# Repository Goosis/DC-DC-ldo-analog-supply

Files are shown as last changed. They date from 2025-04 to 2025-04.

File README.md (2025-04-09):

#  Dual-Stage Power Supply (DC-DC Buck + LDO)

**Input:** 6–10V DC  
**Output 1:** 4V @ 3.5A (Buck Converter)  
**Output 2:** 2.6V @ 1.7A (LDO Regulator)  
**Design Tool:** KiCad  
**ICs:** TPS56837H (Buck), TPS7A53B (LDO)

---

##  Description

This is a compact, efficient two-stage power supply designed for low-noise and high-current applications. It converts a 6–10V DC input into:

- 4V @ 3.5A via DC-DC Buck (TPS56837H)
- 2.6V @ 1.7A via LDO (TPS7A53B)

The design was based on official **Texas Instruments datasheets**, simulation tools, and PCB manufacturer guidelines. Great care was taken in layout, thermal management, and ground isolation.

---

##  Key Components

| Stage | IC | Vin | Vout | Iout Max | Notes |
|---|---|---|---|---|---|
| Buck  | TPS56837H | 6–10 V | 4 V  | 3.5 A | Synchronous, 500 kHz |
| LDO | TPS7A53B | 4 V | 2.6 V| 1.7 A | Ultra-low noise, high PSRR |

---

##  Layout Design vs TI Recommendation

This PCB layout was designed by following layout principles from the **TPS56837H datasheet**.

<table>
  <tr>
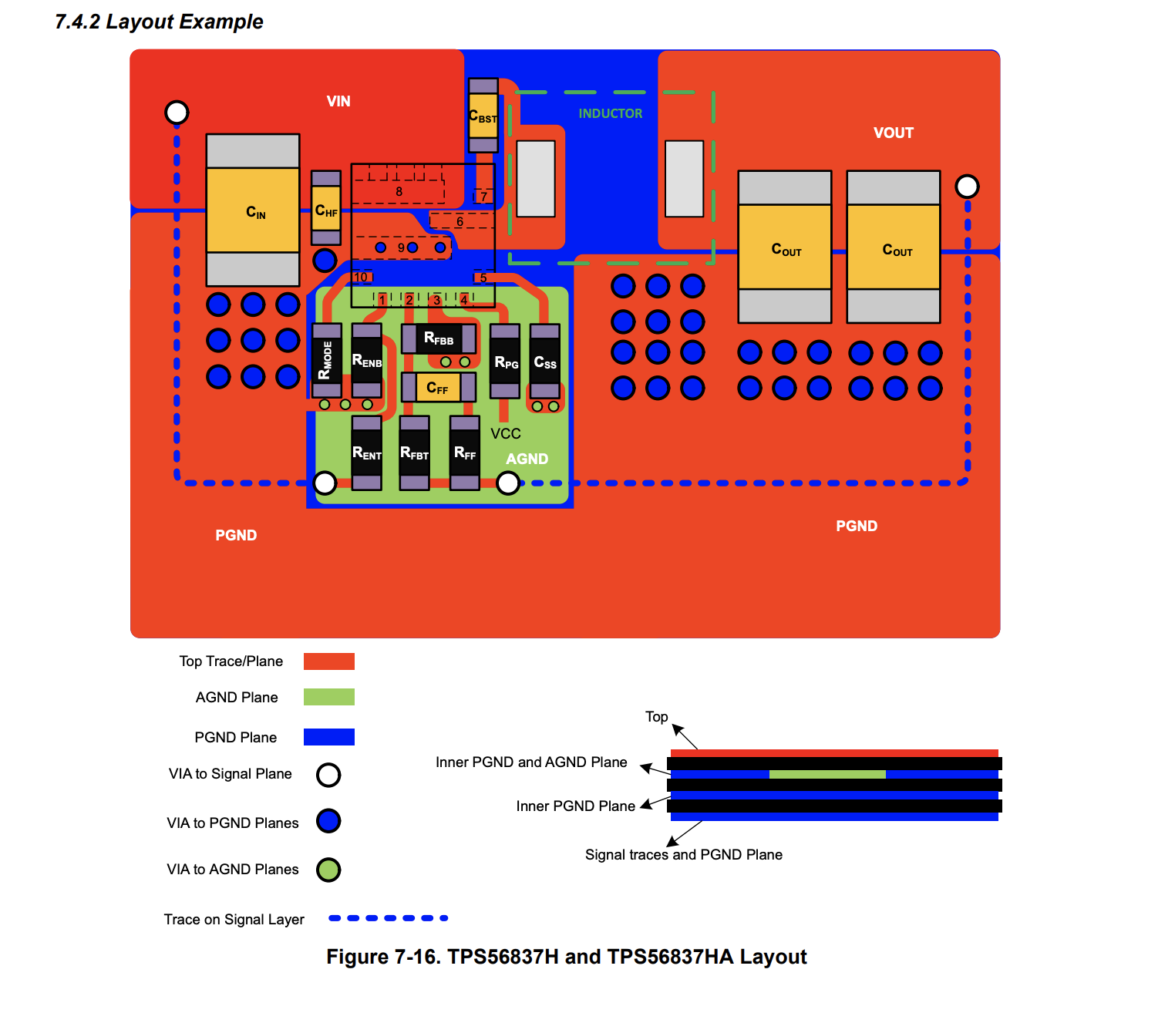
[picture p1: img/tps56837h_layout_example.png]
    <td><b>TI Recommended Layout</b><br/></td>
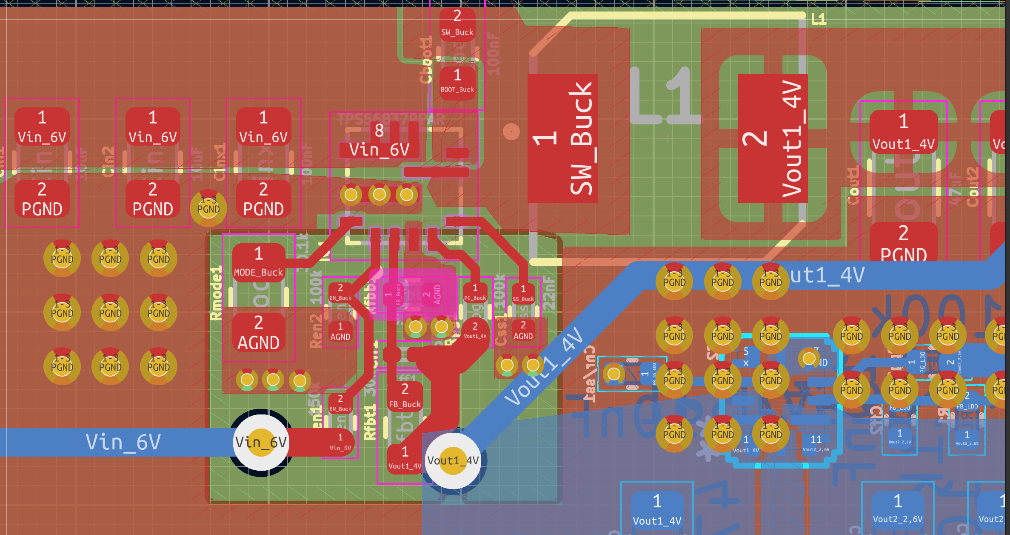
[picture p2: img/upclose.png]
    <td><b>My PCB Layout (KiCad)</b><br/></td>
  </tr>
</table>

 **Matched Design Features:**
- Short loops for high-current paths (Cin → SW → Inductor → Cout)
- Correct placement of decoupling capacitors near IC pins
- AGND and PGND separation via internal planes and via stitching
- Wide copper traces sized according to 3.5A requirement
- Respect of layout zones for analog feedback and control

---
---

##  PSpice Simulation

The design was simulated in PSpice using vendor-provided models for both the buck converter (TPS56837H) and LDO (TPS7A5301).  
This helped verify soft-start behavior, regulation stability, and output timing before fabrication.

<table>
  <tr>
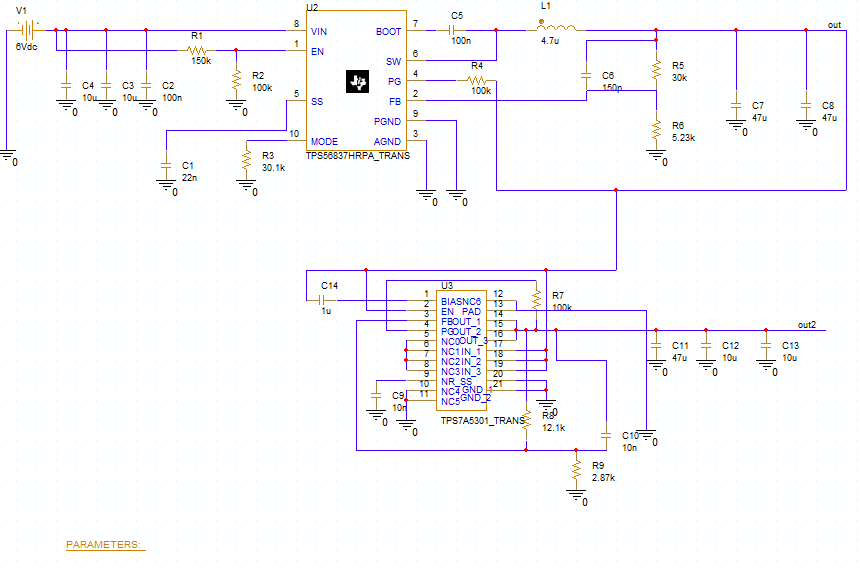
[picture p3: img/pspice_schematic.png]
    <td><b>Schematic (PSpice)</b><br/></td>
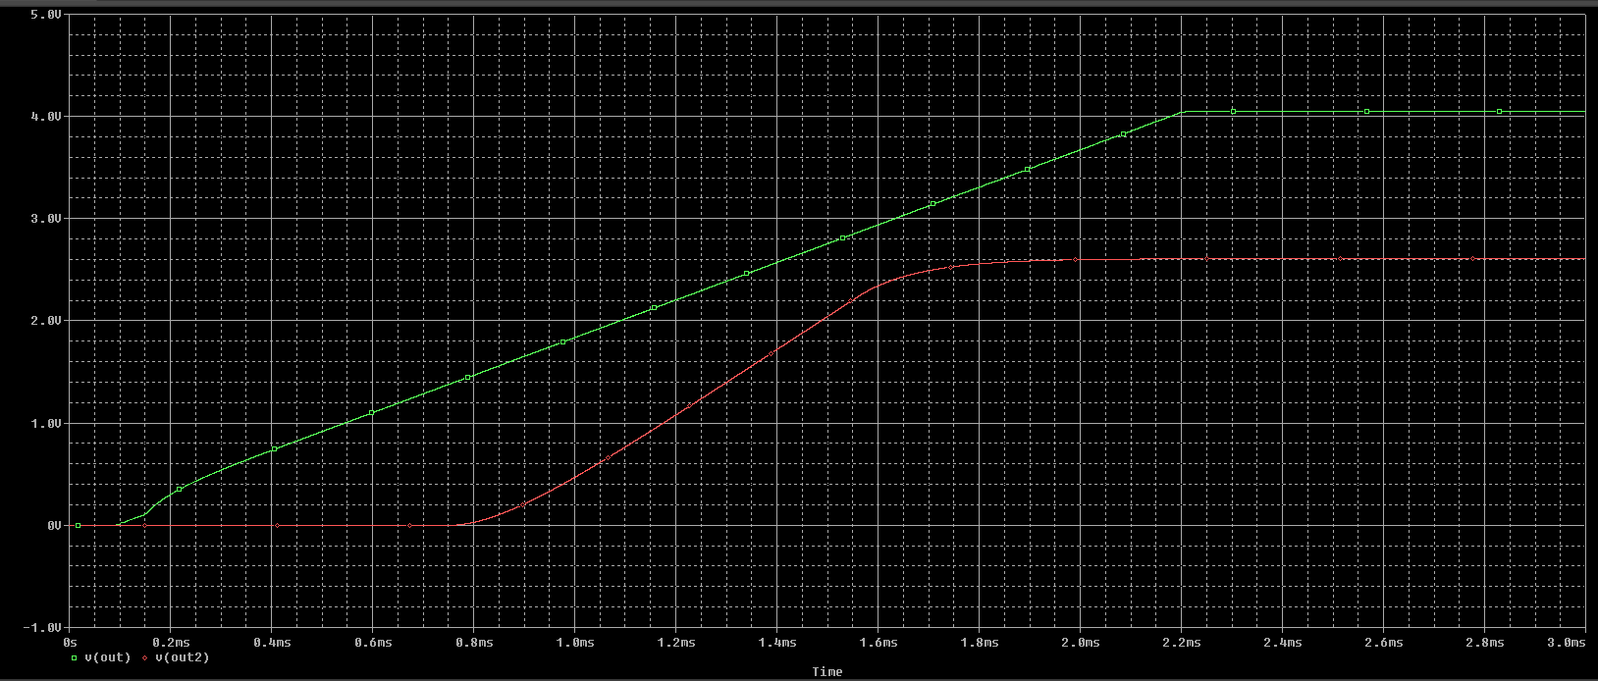
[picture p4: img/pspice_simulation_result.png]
    <td><b>Simulation Result</b><br/></td>
  </tr>
</table>

Green = Vout1 (4 V)  
Red = Vout2 (2.6 V)

The simulation shows proper soft-start ramp-up and sequential regulation, matching expectations.

Simulation files are aviable on my [Google Drive](https://drive.google.com/drive/folders/1zhOBsbE7j7mKasGqCcKV4JfBKCOTLMK9?hl=cs)

##  Images

### Schematic  
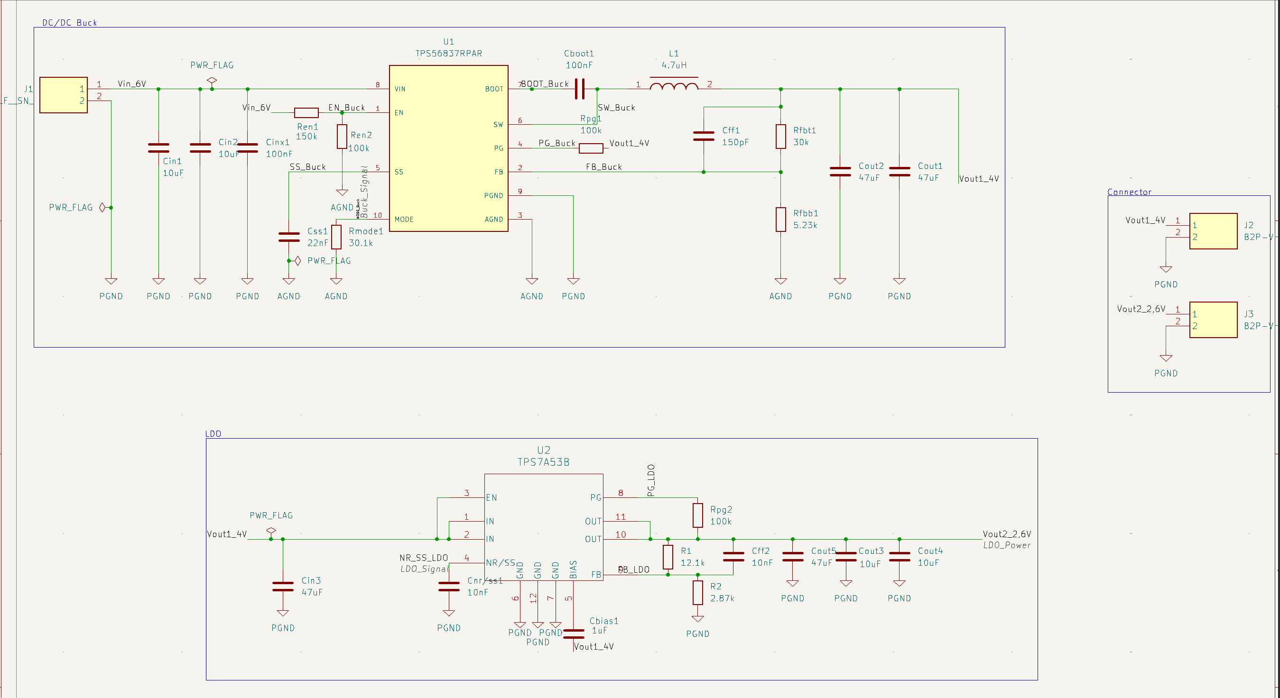
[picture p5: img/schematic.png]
schematic


### PCB Layout (Top Layer)  
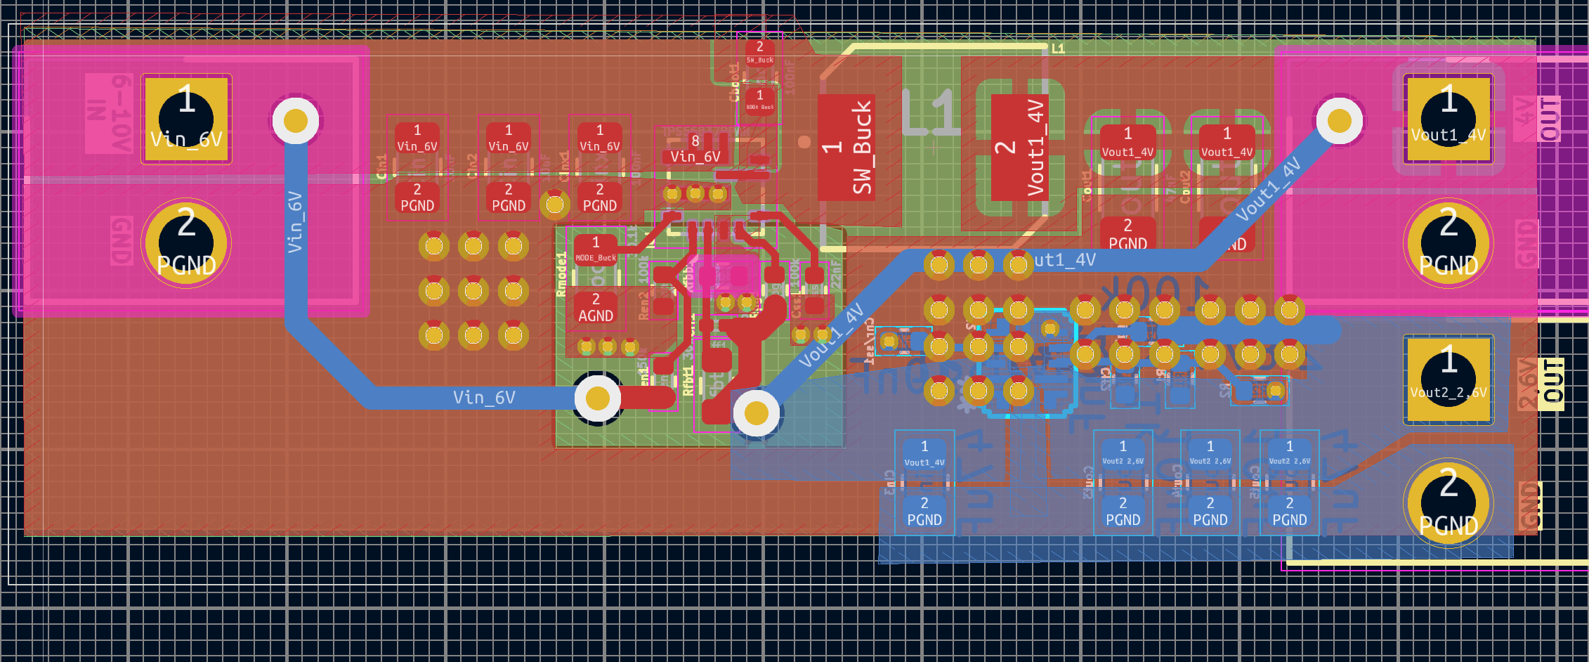
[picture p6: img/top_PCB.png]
PCB Top Layer


### 3D View  
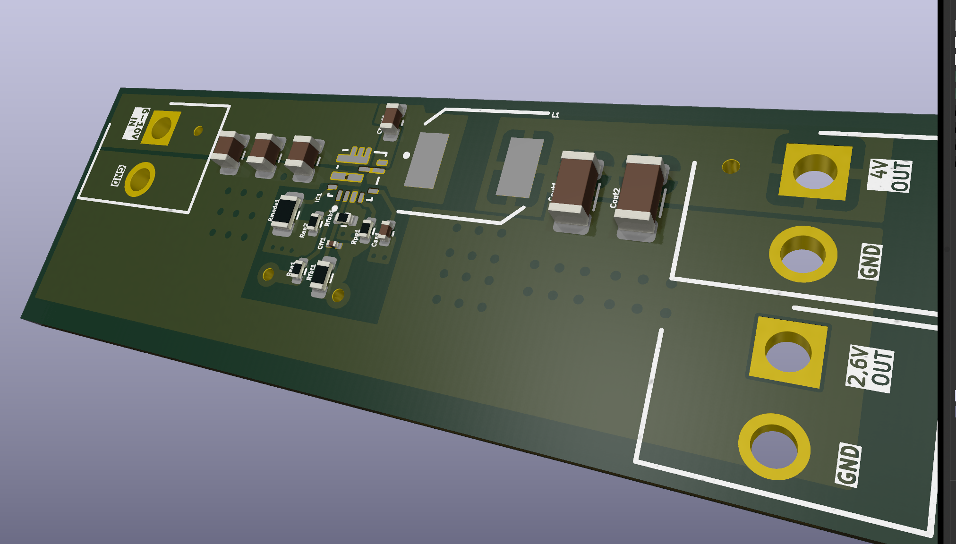
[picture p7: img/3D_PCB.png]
3D View


---

## ⚠️ Design Challenges & Fixes

###  LDO BIAS Pin Not Connected

In the first revision, the **BIAS pin** of the LDO (TPS7A53B) was left floating.  
According to [section 8.3.1.2 of the datasheet](https://www.ti.com/lit/ds/symlink/tps7a53b.pdf#page=19), this causes the output to **follow the input voltage** instead of regulating — which is exactly what happened.

📌 **Fix:** Connected BIAS to VIN (4 V) and added a 1 µF capacitor to GND, as recommended in the datasheet.

---

###  Incorrect EN Pin Logic on Buck Converter

Initially, the **EN pin** of the buck converter was connected to its own output (VOUT), assuming it would enable itself after power-up.  
However, this caused the converter to stay disabled at startup.

📌 **Fix:** Connected EN to VIN through a **resistor divider**, ensuring a valid logic-high signal at startup. This resolved the issue and allowed proper converter initialization.

---

###  TI-Provided Footprint Had Pad Issues

The **footprint from TI's UltraLibrarian export** for the TPS7A53B had issues:
- Some **pads were incorrectly shaped or numbered**
- **Routing was blocked** due to KiCad DRC violations

📌 **Fix:** Manually edited the footprint in **KiCad Footprint Editor** to:
- Adjust pad shapes and positions
- Fix pin numbering
- Ensure proper copper connection and DRC clearance

---

These issues were identified during layout review and early testing, and fixed in preparation for the next board revision.

---

##  Project Files

- `/schematic/` — KiCad schematic (`.kicad_sch`)  
- `/pcb/` — KiCad board layout (`.kicad_pcb`)  
- `/gerbers/` — Gerber files for fabrication  
- `/bom/` — Bill of Materials  
- `/pdf/` — PDF exports of schematic and layout

---

##  Tools & Calculators Used

- [TI Webench Power Designer](https://webench.ti.com/power-designer/)
- [ChipDip Voltage Divider Calculator](https://www.chipdip.ru/calc/voltage-divider)
- [Trace Width Calculator (AdvancedPCB)](https://www.advancedpcb.com/en-us/tools/trace-width-calculator/)
- [Via Properties Calculator (911EDA)](https://www.911eda.com/pcb-design-calculators/via-properties-calculator/)
- [JLCPCB Capabilities](https://jlcpcb.com/capabilities/pcb-capabilities)

---

## ✅ Project Status

- [x] Schematic complete  
- [x] PCB layout finished  
- [x] BOM generated  
- [x] Layout verified vs datasheet  
- [ ] PCB ordered  
- [ ] Load testing  
- [ ] Ripple and thermal validation

---

## 📚 References

- [TPS56837H Datasheet](https://www.ti.com/product/TPS56837H)
- [TPS7A53B Datasheet](https://www.ti.com/product/TPS7A53B)
- [KiCad Docs](https://docs.kicad.org/)

---

> 💬 Suggestions, improvements, or critiques are welcome. This design is still open for review.

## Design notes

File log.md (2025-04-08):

## Day 1 – March 25

- Defined system requirements: Vin = 6–10 V, Vout1 = 4 V, Iout1 = 3.5 A, Vout2, Iout2 = 2.6 V
- Chose a two-stage power topology: DC-DC buck converter followed by a low-noise LDO
- Selected components:
  - **TPS56837H** (buck converter, 6 A)
  - **TPS7A53B** (LDO regulator, 3 A)
- For **TPS56837H**:
  - Used the [TI WEBENCH Power Designer](https://webench.ti.com/) to calculate values for external components (inductor, input/output capacitors, feedback resistors)
  - Reviewed layout and footprint recommendations in the datasheet (package, thermal pad, via placement)
- For **TPS7A53B**:
  - Manually calculated the feedback resistor values using the datasheet formula:
    \[
    V_{OUT} = V_{REF} \cdot \left(1 + \frac{R_1}{R_2} \right)
    \]
    with V<sub>REF</sub> = 0.5 V
  - Selected R1 = 12.1 kΩ, R2 = 2.87 kΩ to achieve Vout ≈ 2.6 V
  - Calculated feedforward capacitor C<sub>FF</sub> ≈ 1.3 nF to place the zero around 10 kHz

## Day 2 – March 27

- **Completed schematic design** for the power system, incorporating the DC-DC buck converter (TPS56837H) followed by the LDO (TPS7A53B).
- **Recalculated component values** for a few parts based on datasheet recommendations.
  - **Updated feedback resistor values** to fine-tune the output voltage for the LDO (TPS7A53B).
  - **Validated output capacitors**: 47uF and 10uF for both input and output filters to meet the recommended capacitance values.
- **Checked for proper component placement and connections** in the schematic:
  - Verified that feedback resistors, capacitors, and power lines are connected correctly.
  - Ensured proper grounding and component orientation for thermal performance and efficiency.
  - **Fixed errors** related to component placement in the layout for power and ground planes.
- **No major issues** found in the design; proceeding with the next steps of layout design and preparation for PCB.

### Day 3 – March 31

- Finalized full BOM for the power subsystem  
- Fixed EN pin bug on the buck converter (added voltage divider from Vin)  
- Created custom net classes in KiCad (`Buck_Power`, `LDO_Signal`, etc.)  
- Assigned nets and set trace widths based on datasheet recommendations  

**Day 4 – April 1**  
- Placed components for the TPS56837H on the PCB.  
- Decided to replace the connectors, as the current ones are too large for a compact layout.  
- Replaced the inductor entirely — the previous one was too large, and the new one is $2 cheaper.
- Marked several capacitors and resistors (0805) to be replaced with 0402 packages for space optimization and better routing.  
→ Will update these footprints and revise the BOM tomorrow.

### Day 5 – April 2

- Had a productive 7-hour session today.  
- Completed component placement in sections and connected all components.  
- Changed the CBOOT1 capacitor package from 0402 to 0603 to comply with clearance rules.  
- Encountered footprint issues for ICs – learned how to modify footprints using the footprint editor.  
- Learned to work with a 4-layer PCB stackup.  
- Tomorrow: will label all components clearly and update the BOM.

- ### Day 6 – April 4
- Updated BOM

- ### Day 6 – April 4
- Completed README.md
- Uploaded files to github

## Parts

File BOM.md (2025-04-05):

### Capacitors

| Reference | Quantity | Value | Footprint | Manufacturer | Price  | Total  | Link |
|---|---|---|---|---|---|---|---|
| Cff1 | 1 | 150pF  | 0603 | KEMET | $0.100 | $0.10  | [Link](https://cz.mouser.com/ProductDetail/Coilcraft/MSS1048-472NLC?qs=zCSbvcPd3pYtZ57pXl6AJA==) |
| Cout1,Cout2 | 2 | 47uF | 1206 | TDK | $0.871 | $1.74  | [Link](https://cz.mouser.com/ProductDetail/TDK/C3216X5R1E476M160AC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) |
| Cout3,Cout4 | 2 | 10uF | 0805 | TAIYO YUDEN  | $0.271 | $0.54  | [Link](https://cz.mouser.com/ProductDetail/TAIYO-YUDEN/TMK212BBJ106MGHT?qs=sBf/b4nBSlfab8x4Ir6OCA==) |
| Cboot1 | 1 | 100nF  | 0603 | KYOCERA AVX | $0.171 | $0.17  | [Link](https://eu.mouser.com/ProductDetail/KYOCERA-AVX/0201YD104KAT2A?qs=%252BdQmOuGyFcFSHNmmxKg%252B7A%3D%3D) |
| Cout5, Cin3 | 2 | 47uF | 0805 | TAIYO YUDEN  | $0.731 | $1.46  | [Link](https://cz.mouser.com/ProductDetail/TAIYO-YUDEN/MLASL21GBB5476MTNA01?qs=tlsG/Ow5FFgOkGqgSpO4Uw==) |
| Cinx1 | 1 | 100nF  | 0805 | MuRata | $0.311 | $0.31  | [Link](https://cz.mouser.com/ProductDetail/Murata-Electronics/GCM21BR71H104KA37L?qs=HH0X151LQklyB3m9dD31Bw%3D%3D) |
| Cin1, Cin2 | 2 | 10uF | 0805 | MuRata | $0.151 | $0.30  | [Link](https://cz.mouser.com/ProductDetail/Murata-Electronics/GRM21BR61E106MA73L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) |
| Css1 | 1 | 22nF | 0402 | MuRata | $0.100 | $0.10  | [Link](https://cz.mouser.com/ProductDetail/Murata-Electronics/GRM155R71C223KA01D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) |
| Cnr/ss1, Cff2 | 2 | 10nF | 0402 | TAIYO YUDEN  | $0.095 | $0.19  | [Link](https://eu.mouser.com/ProductDetail/TAIYO-YUDEN/MSASE042SB5103KWNA01?qs=tlsG%2FOw5FFgLDNWOywOLGg%3D%3D) |

### ICs

| Reference | Quantity | Value | Footprint | Manufacturer | Price  | Total  | Link |
|---|---|---|---|---|---|---|---|
| TPS56837H | 1 | - | TPS56837HARPAR | Texas Instruments  | $2.061 | $2.06  | [Link](https://www.ti.com/product/TPS56837H#all) |
| TPS7A53B | 1 | - | TPS7A53B | Texas Instruments  | $2.404 | $2.40  | [Link](https://www.ti.com/product/TPS7A53B) |

### Other

| Reference | Quantity | Value | Footprint | Manufacturer | Price  | Total  | Link |
|---|---|---|---|---|---|---|---|
| L1 | 1 | 4.7uH  | SPM6530 | TDK | $0.912 | $0.912  | [Link](https://eu.mouser.com/ProductDetail/TDK/SPM6530T-4R7M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) |
| J1, J2, J3  | 3 | 2 pins  | - | Molex | $0.228 | $0.684  | [Link](https://eu.mouser.com/ProductDetail/Molex/26-60-4020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) |

### Resistors

| Reference | Quantity | Value | Footprint | Manufacturer | Price  | Total  | Link |
|---|---|---|---|---|---|---|---|
| Rpg1, Rpg2, Ren1 | 3 | 100kOhm | 0402 | VishayDale | $0.100 | $0.30  | [Link](https://cz.mouser.com/ProductDetail/Vishay-Dale/CRCW0402100KFKED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) |
| Ren2 | 1 | 150 kOhms | 0402 | YAGEO | $0.12 | $0.12  | [Link](https://cz.mouser.com/ProductDetail/Bourns/CR0402-FX-1503GLF?qs=sGAEpiMZZMtlubZbdhIBICGkyIRIR3aIoYCmJyeepGY%3D) |
| Rfbt1 | 1 | 30 kOhms  | 0603 | YAGEO | $0.111 | $0.11  | [Link](https://cz.mouser.com/ProductDetail/YAGEO/RC0603FR-0730KL?qs=diQw95jMAeNFr44yr782FQ%3D%3D) |
| Rfbb1 | 1 | 5.23 kOhms| 0402 | VishayDale | $0.100 | $0.10  | [Link](https://cz.mouser.com/ProductDetail/Vishay-Dale/CRCW04025K23FKED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) |
| R2 | 1 | 2.87kOhm  | 0402 | YAGEO | $0.124 | $0.12  | [Link](https://eu.mouser.com/ProductDetail/YAGEO/RC0100FR-072K87L?qs=tggtontpCXMGft6%252B2PgPnw%3D%3D) |
| R1 | 1 | 12.1kOhm  | 0402 | VishayDale | $0.171 | $0.17  | [Link](https://eu.mouser.com/ProductDetail/Vishay-Dale/CRCW010012K1FREL?qs=r5DSvlrkXmKL%252BfFur1RTrw%3D%3D) |
| Rmode1 | 1 | 30.1kOhm  | 0805 | KOA Speer | $0.233 | $0.23  | [Link](https://cz.mouser.com/ProductDetail/KOA-Speer/SG73P2ARTTD3012F?qs=Y0Uzf4wQF3ldSzmG%252BQ6ZTQ%3D%3D) |

**Total Cost: $12,14**

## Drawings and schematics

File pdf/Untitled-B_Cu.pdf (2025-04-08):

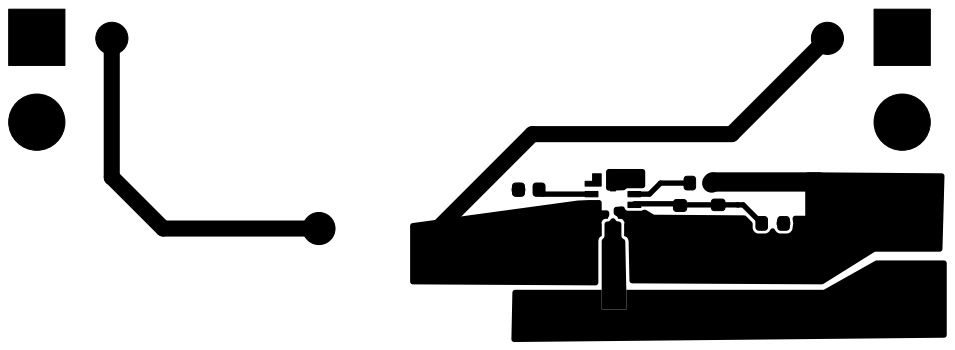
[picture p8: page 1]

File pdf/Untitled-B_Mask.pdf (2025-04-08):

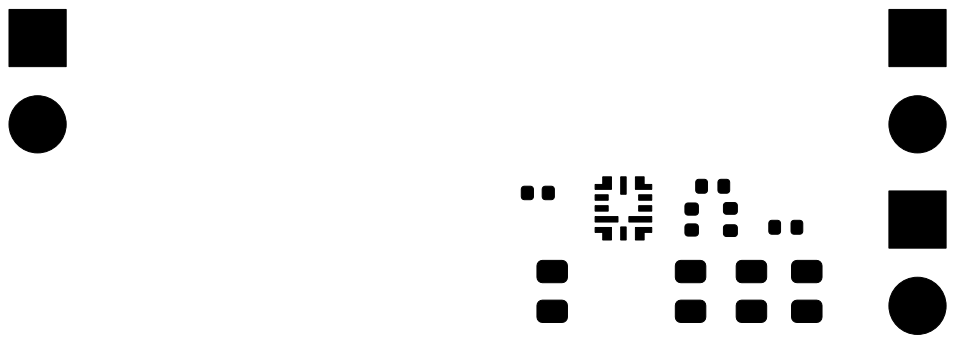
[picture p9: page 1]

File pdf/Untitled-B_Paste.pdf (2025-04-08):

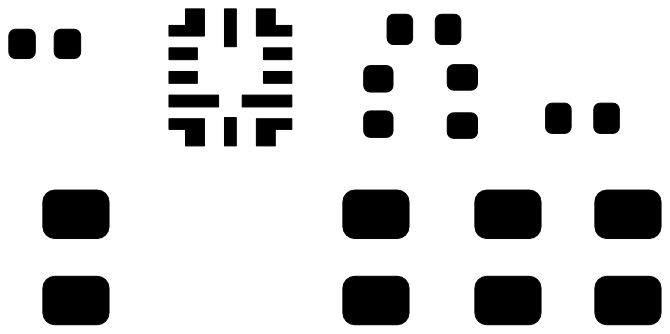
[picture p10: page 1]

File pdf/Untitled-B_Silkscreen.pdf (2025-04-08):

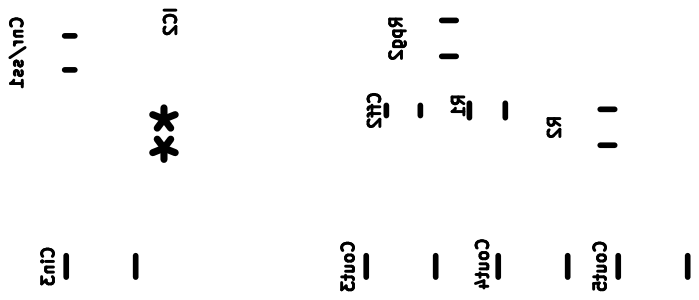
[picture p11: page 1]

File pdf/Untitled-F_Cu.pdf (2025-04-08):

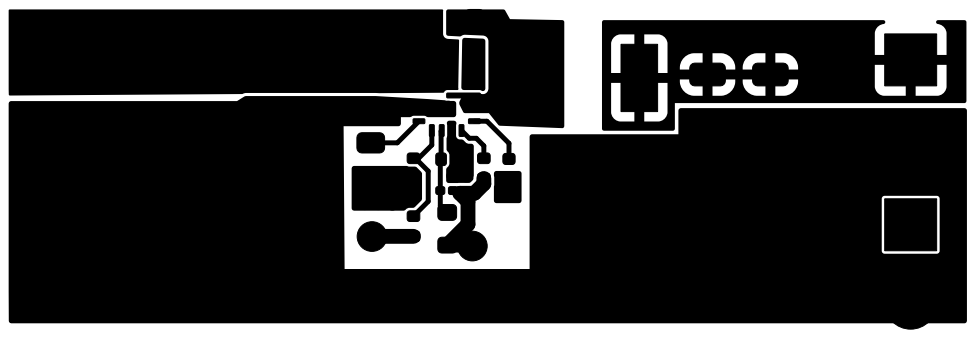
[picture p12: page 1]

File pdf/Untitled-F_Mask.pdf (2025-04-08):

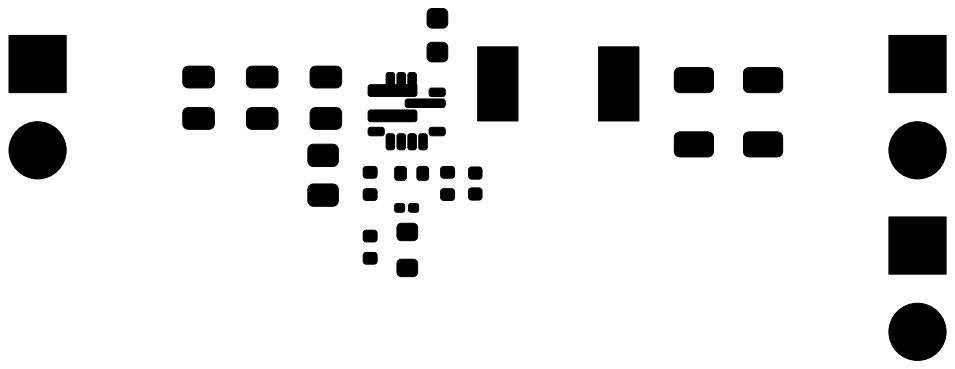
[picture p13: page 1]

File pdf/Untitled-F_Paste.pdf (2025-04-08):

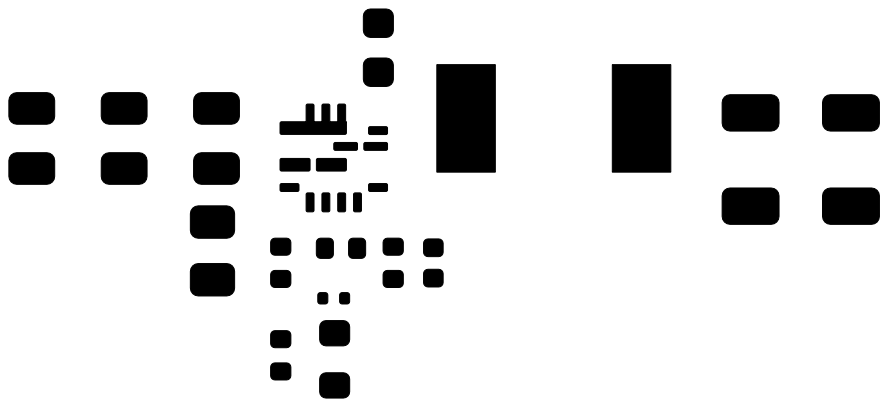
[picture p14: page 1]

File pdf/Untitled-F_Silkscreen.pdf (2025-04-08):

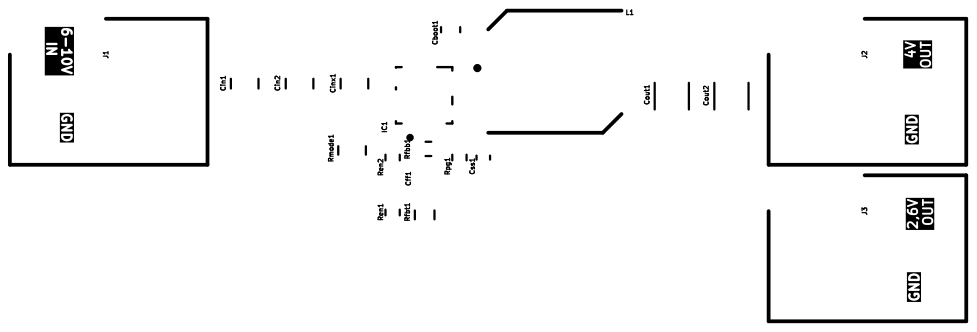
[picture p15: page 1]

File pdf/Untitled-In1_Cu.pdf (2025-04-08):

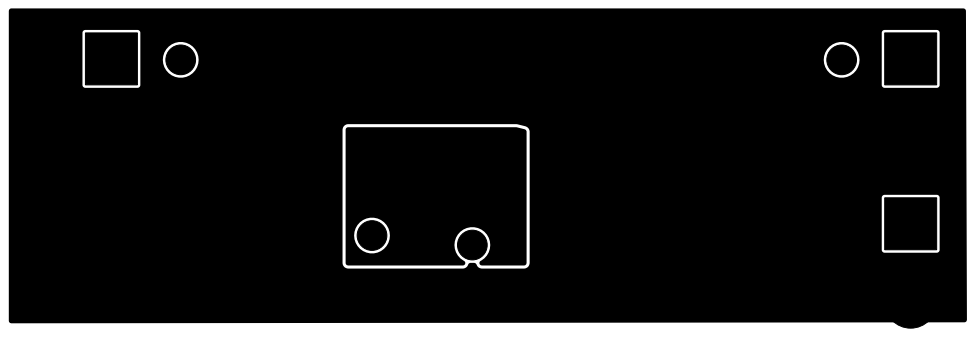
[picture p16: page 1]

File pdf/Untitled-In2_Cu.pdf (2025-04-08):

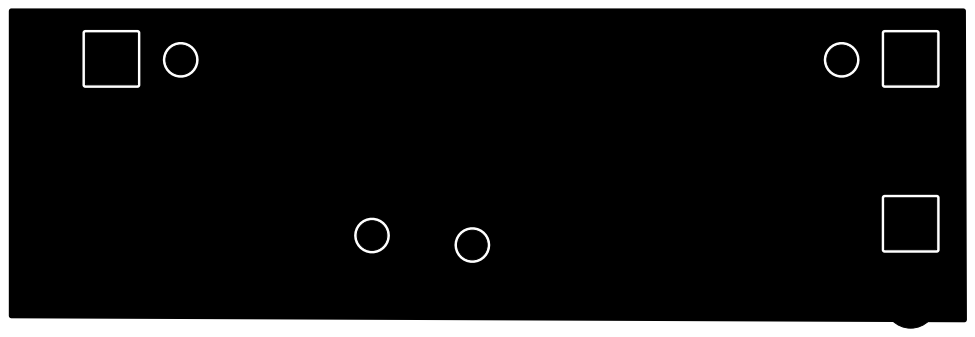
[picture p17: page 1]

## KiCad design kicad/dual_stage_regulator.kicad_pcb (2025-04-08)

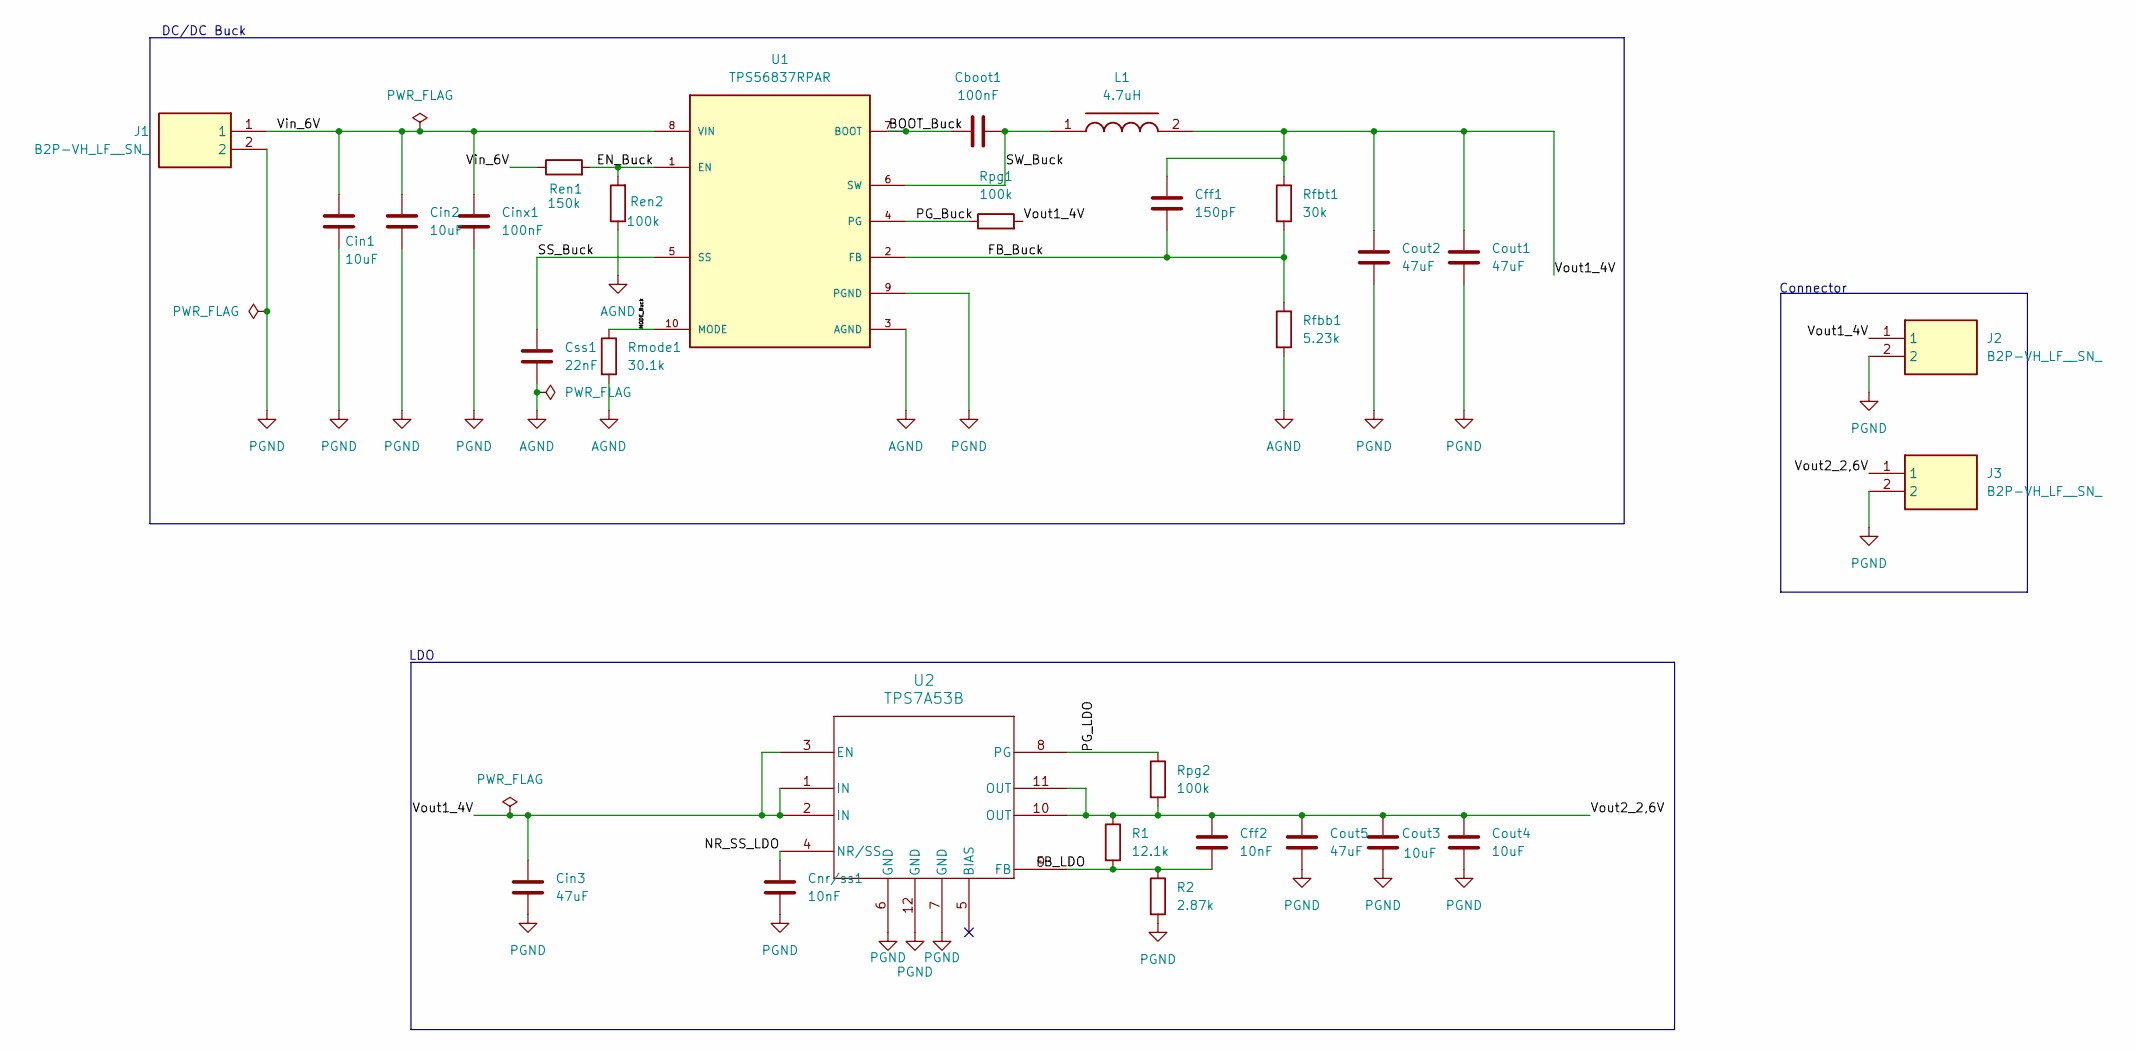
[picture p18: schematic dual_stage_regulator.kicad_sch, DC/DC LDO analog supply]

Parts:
Cboot1: 100nF; C_0603_1608Metric
Cff1: 150pF; C_0201_0603Metric
Cff2: 10nF; C_0402_1005Metric
Cin1, Cin2: 10uF; C_0805_2012Metric
Cin3: 47uF; R_0805_2012Metric
Cinx1: 100nF; C_0805_2012Metric
Cnr/ss1: 10nF; C_0402_1005Metric
Cout1, Cout2: 47uF; C_1206_3216Metric
Cout3, Cout4: 10uF; R_0805_2012Metric
Cout5: 47uF; R_0805_2012Metric
Css1: 22nF; C_0402_1005Metric
J1, J2, J3: B2P-VH_LF__SN_; SHDR2W155P0X396_1X2_777X1001X1184P; Mouser Part Number N/A
L1: 4.7uH; SPM6530; Mouser Part Number 810-SPM6530T-4R7M
R1: 12.1k; R_0402_1005Metric
R2: 2.87k; R_0402_1005Metric
Ren1: 150k; R_0402_1005Metric
Ren2: 100k; R_0402_1005Metric
Rfbb1: 5.23k; R_0402_1005Metric
Rfbt1: 30k; R_0603_1608Metric
Rmode1: 30.1k; R_0805_2012Metric
Rpg1, Rpg2: 100k; R_0402_1005Metric
U1: TPS56837RPAR; CONV_TPS56837RPAR; PARTREV A
U2: TPS7A53B; VQFN-HR12_RPS_TEX

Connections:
/BOOT_Buck: Cboot1.1, U1.7 (BOOT); also elsewhere on the board
/EN_Buck: Ren1.2, Ren2.2, U1.1 (EN); also elsewhere on the board
/FB_Buck: Cff1.2, Rfbb1.1, Rfbt1.2, U1.2 (FB); also elsewhere on the board
/FB_LDO: Cff2.2, R1.2, R2.1, U2.9 (FB); also elsewhere on the board
/MODE_Buck: Rmode1.1, U1.10 (MODE); also elsewhere on the board
/NR_SS_LDO: Cnr/ss1.1, U2.4 (NR/SS); also elsewhere on the board
/PG_Buck: Rpg1.1, U1.4 (PG); also elsewhere on the board
/PG_LDO: Rpg2.1, U2.8 (PG); also elsewhere on the board
/SS_Buck: Css1.1, U1.5 (SS); also elsewhere on the board
/SW_Buck: Cboot1.2, L1.1, U1.6 (SW); also elsewhere on the board
/Vin_6V: Cin1.1, Cin2.1, Cinx1.1, J1.1, Ren1.1, U1.8 (VIN); also elsewhere on the board
/Vout1_4V: Cff1.1, Cin3.1, Cout1.1, Cout2.1, J2.1, L1.2, Rfbt1.1, Rpg1.2, U2.1 (IN), U2.2 (IN), U2.3 (EN); also elsewhere on the board
/Vout2_2,6V: Cff2.1, Cout3.1, Cout4.1, Cout5.1, J3.1, R1.1, Rpg2.2, U2.10 (OUT), U2.11 (OUT); also elsewhere on the board
AGND: Css1.2, Ren2.1, Rfbb1.2, Rmode1.2, U1.3 (AGND); also elsewhere on the board
PGND: Cin1.2, Cin2.2, Cin3.2, Cinx1.2, Cnr/ss1.2, Cout1.2, Cout2.2, Cout3.2, Cout4.2, Cout5.2, J1.2, J2.2, J3.2, R2.2, U1.9 (PGND), U2.6 (GND), U2.7 (GND), U2.12 (GND); also elsewhere on the board

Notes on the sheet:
DC/DC Buck
LDO
Connector

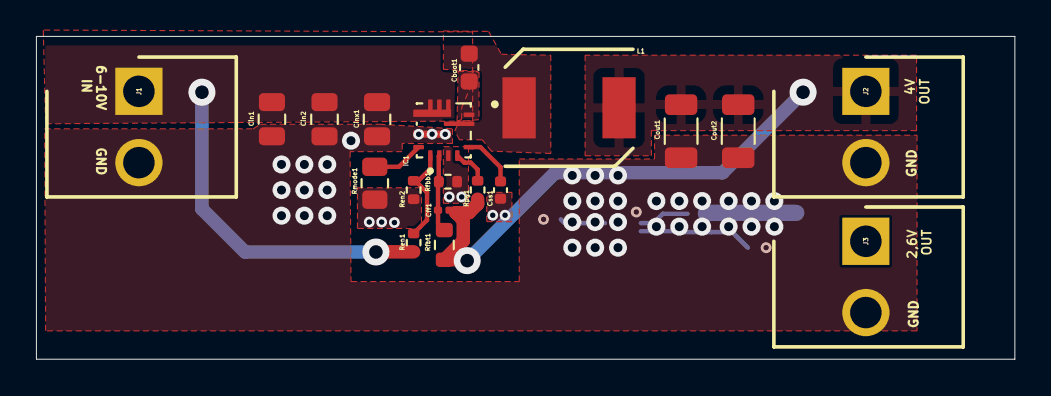
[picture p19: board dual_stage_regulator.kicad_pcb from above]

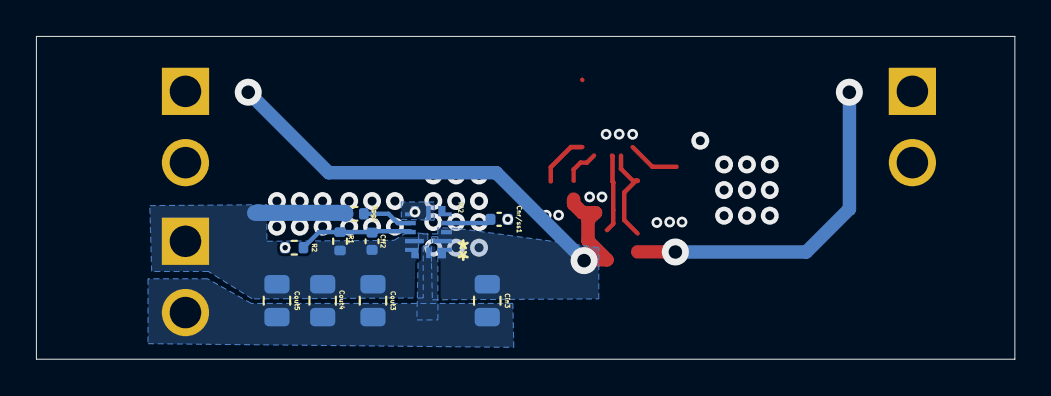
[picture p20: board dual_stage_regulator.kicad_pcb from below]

Board: 4 copper layers, 54.4 x 17.9 mm, 29 parts (10 on the bottom side), 15 nets.

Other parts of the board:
IC1: TPS56837RPAR; CONV_TPS56837RPAR
IC2: TPS7A53B; VQFN-HR12_RPS_TEX

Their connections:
/BOOT_Buck: IC1.7 (BOOT); also elsewhere on the board
/EN_Buck: IC1.1 (EN); also elsewhere on the board
/FB_Buck: IC1.2 (FB); also elsewhere on the board
/FB_LDO: IC2.9 (FB); also elsewhere on the board
/MODE_Buck: IC1.10 (MODE); also elsewhere on the board
/NR_SS_LDO: IC2.4 (NR/SS); also elsewhere on the board
/PG_Buck: IC1.4 (PG); also elsewhere on the board
/PG_LDO: IC2.8 (PG); also elsewhere on the board
/SS_Buck: IC1.5 (SS); also elsewhere on the board
/SW_Buck: IC1.6 (SW); also elsewhere on the board
/Vin_6V: IC1.8 (VIN); also elsewhere on the board
/Vout1_4V: IC2.1 (IN), IC2.2 (IN), IC2.3 (EN); also elsewhere on the board
/Vout2_2,6V: IC2.10 (OUT), IC2.11 (OUT); also elsewhere on the board
AGND: IC1.3 (AGND); also elsewhere on the board
PGND: IC1.9 (PGND), IC2.6 (GND), IC2.7 (GND), IC2.12 (GND); also elsewhere on the board
